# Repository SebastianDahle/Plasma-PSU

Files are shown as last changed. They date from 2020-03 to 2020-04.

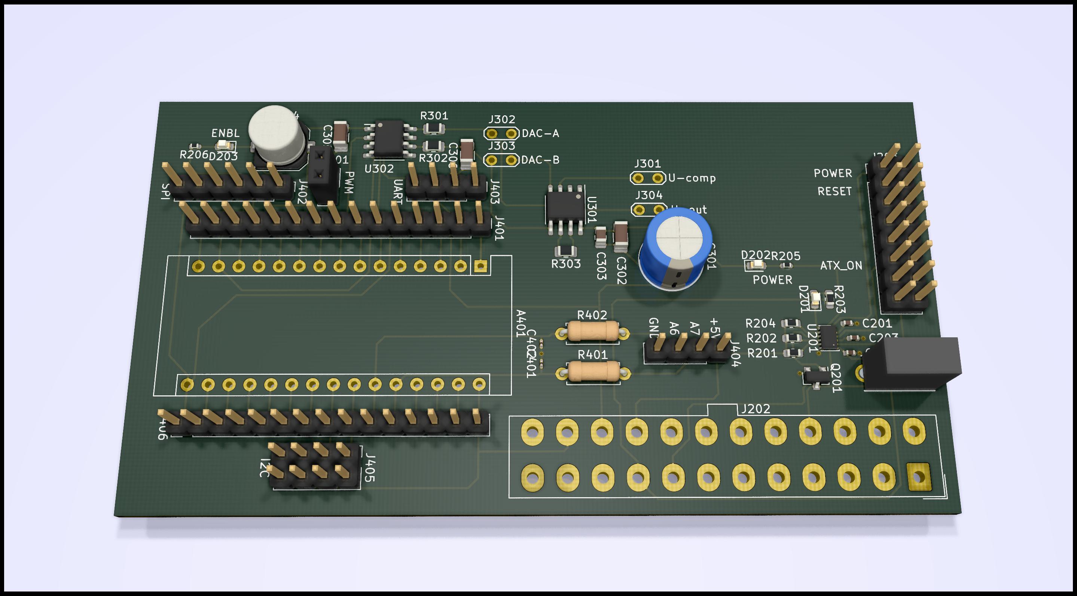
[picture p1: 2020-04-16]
Test-PCB_for_Arduino-DAC/Test-PCB_for_Arduino-DAC_002.jpg

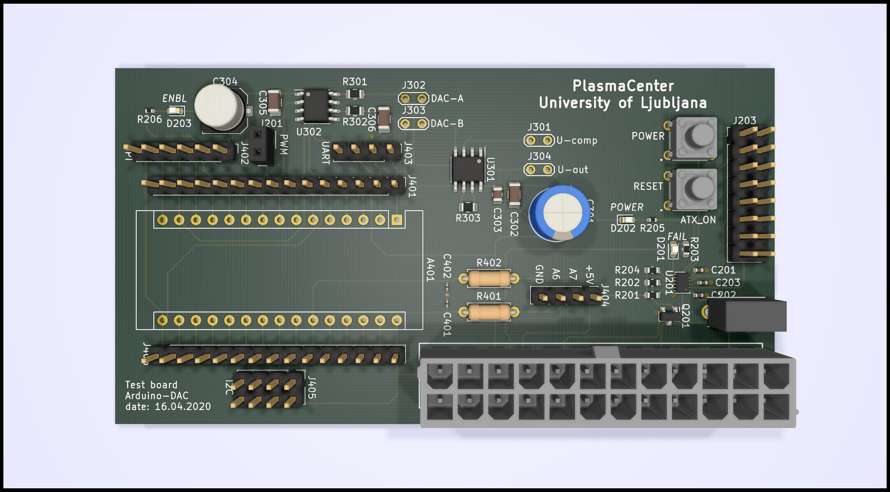
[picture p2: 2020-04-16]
Test-PCB_for_Arduino-DAC/Test-PCB_for_Arduino-DAC_004.jpg

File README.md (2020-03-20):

View this project on [CADLAB.io](https://cadlab.io/project/22638). 

# Plasma-PSU
Semi-professional HV power supply for various plasma applications, including Gliding Arcs, Dielectric Barrier Discharges, or School demonstrations. The design shall be suited for use in a laboratory environment, but simple and cheap to allow for uptake in DIY communities.

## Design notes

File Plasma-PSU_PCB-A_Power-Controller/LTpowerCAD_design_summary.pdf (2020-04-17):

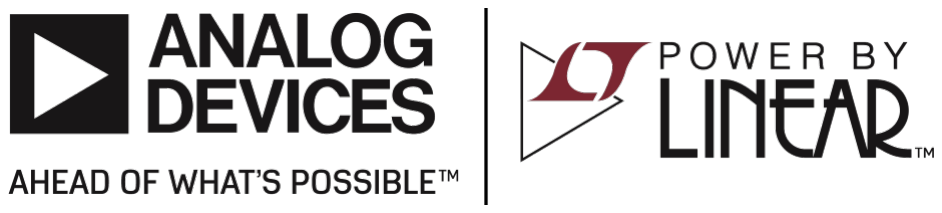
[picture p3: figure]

Printed : 04.17.2020 | Copyright © 2014 Analog Devices Inc.

## Designer :

## Project Date : 9/2014

## Project Name : Demo Board DC1641A

## Output Rails : Vout1 = 34,91V / 12A (max.)

## Vin : 10V (min.), 12V (nom.), 14V (max.)

# LTC3786 Supply Design Summary Report

## Output Rails : Vout1 = 34,91V / 12A (max.)

## Vin : 10V (min.), 12V (nom.), 14V (max.)

## LTC3786 Solution - Simplified Schematic

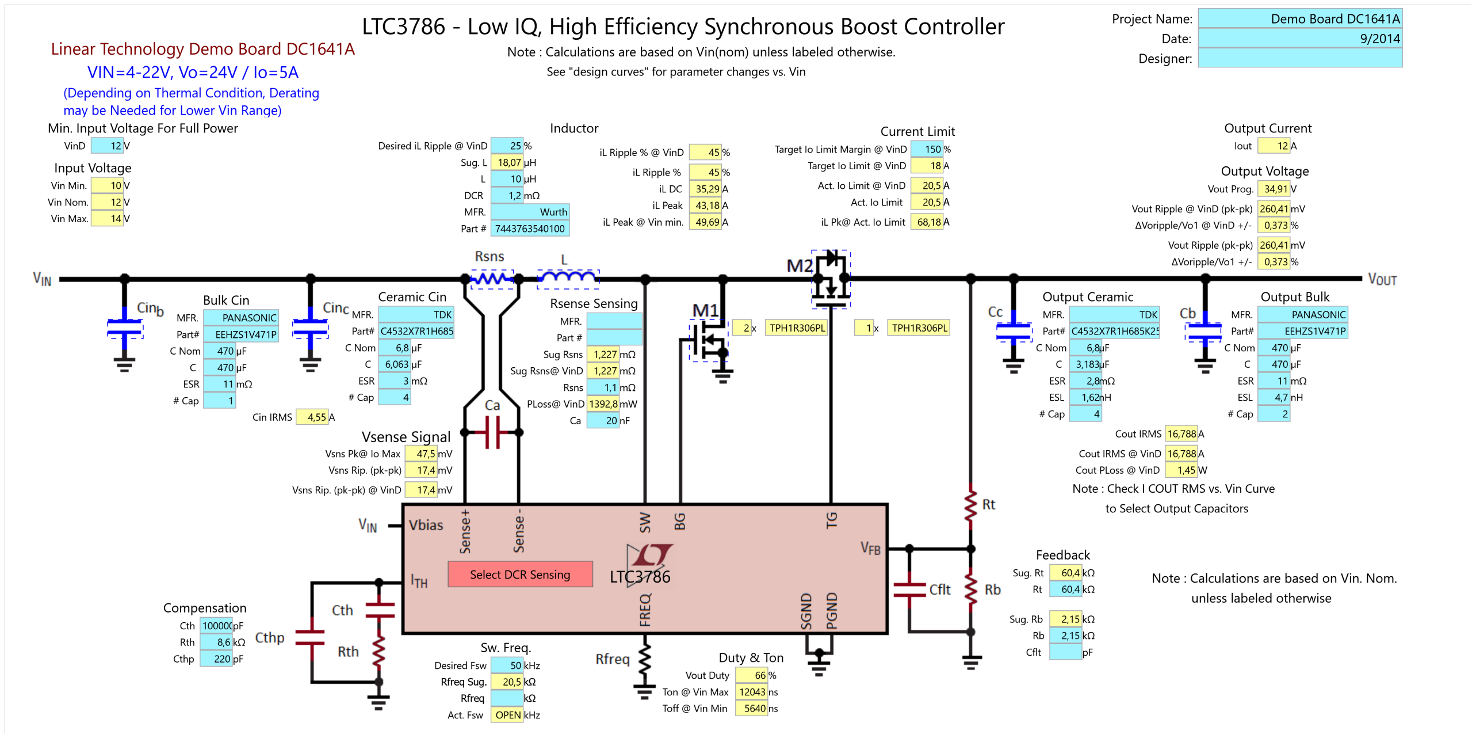
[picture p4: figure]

## Rail # 1 : Vin = 12V, Vout1 = 34,91V

## LTC3786 Solution - Efficiency & Loss Estimations

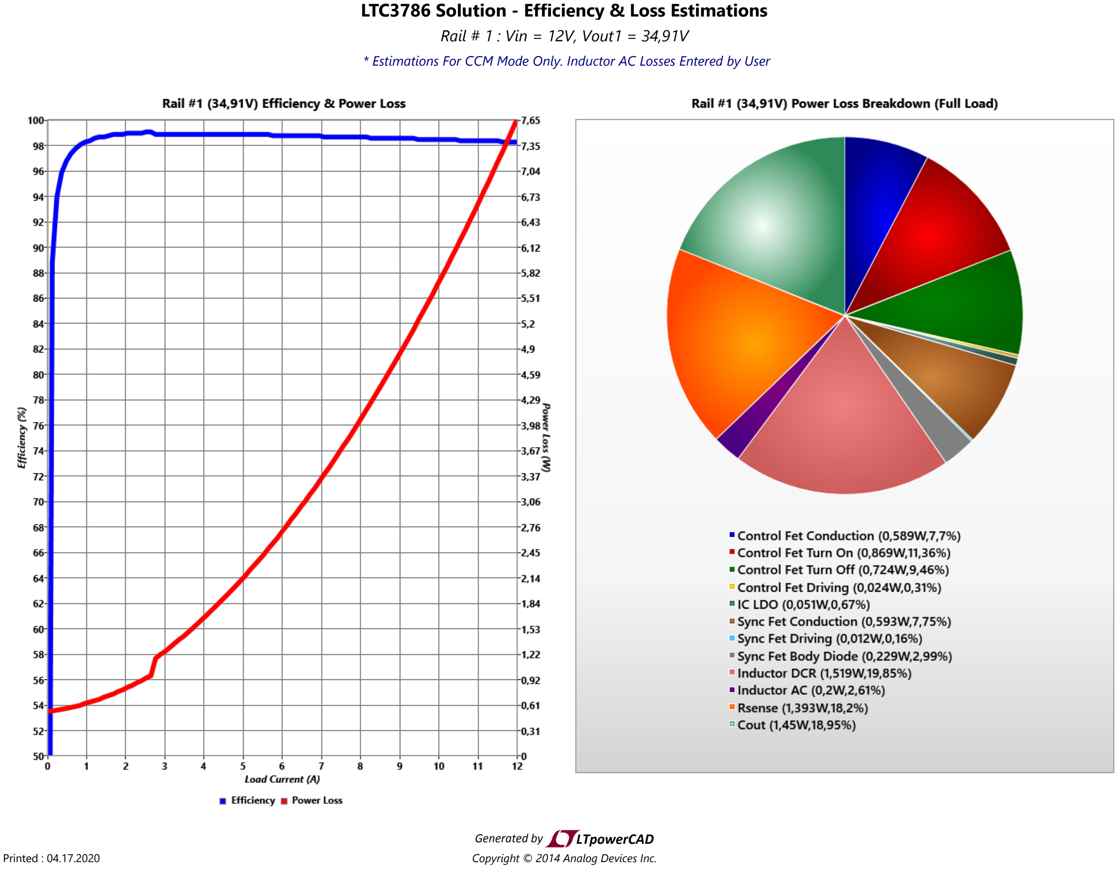
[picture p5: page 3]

### * Estimations For CCM Mode Only. Inductor AC Losses Entered by User

### * Estimations For CCM Mode Only. Estimations Based On Small Signal Avg. Model

## Rail # 1 : Vin = 12V, Vout1 = 34,91V, Iout1 = 1A

## LTC3786 Solution - Loop Gain & Load Transient Estimations

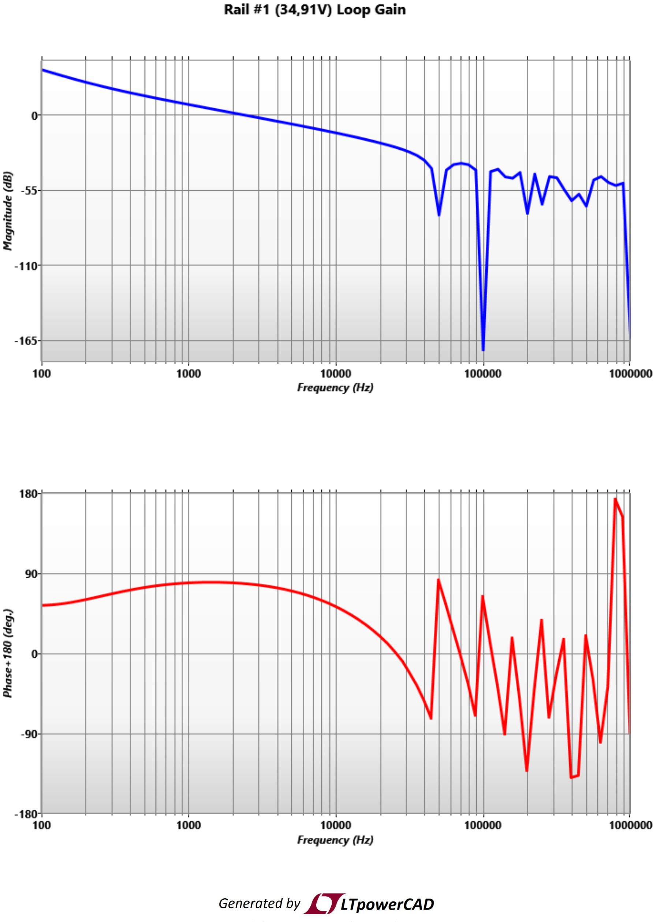
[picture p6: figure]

## LTC3786 Solution - Summary

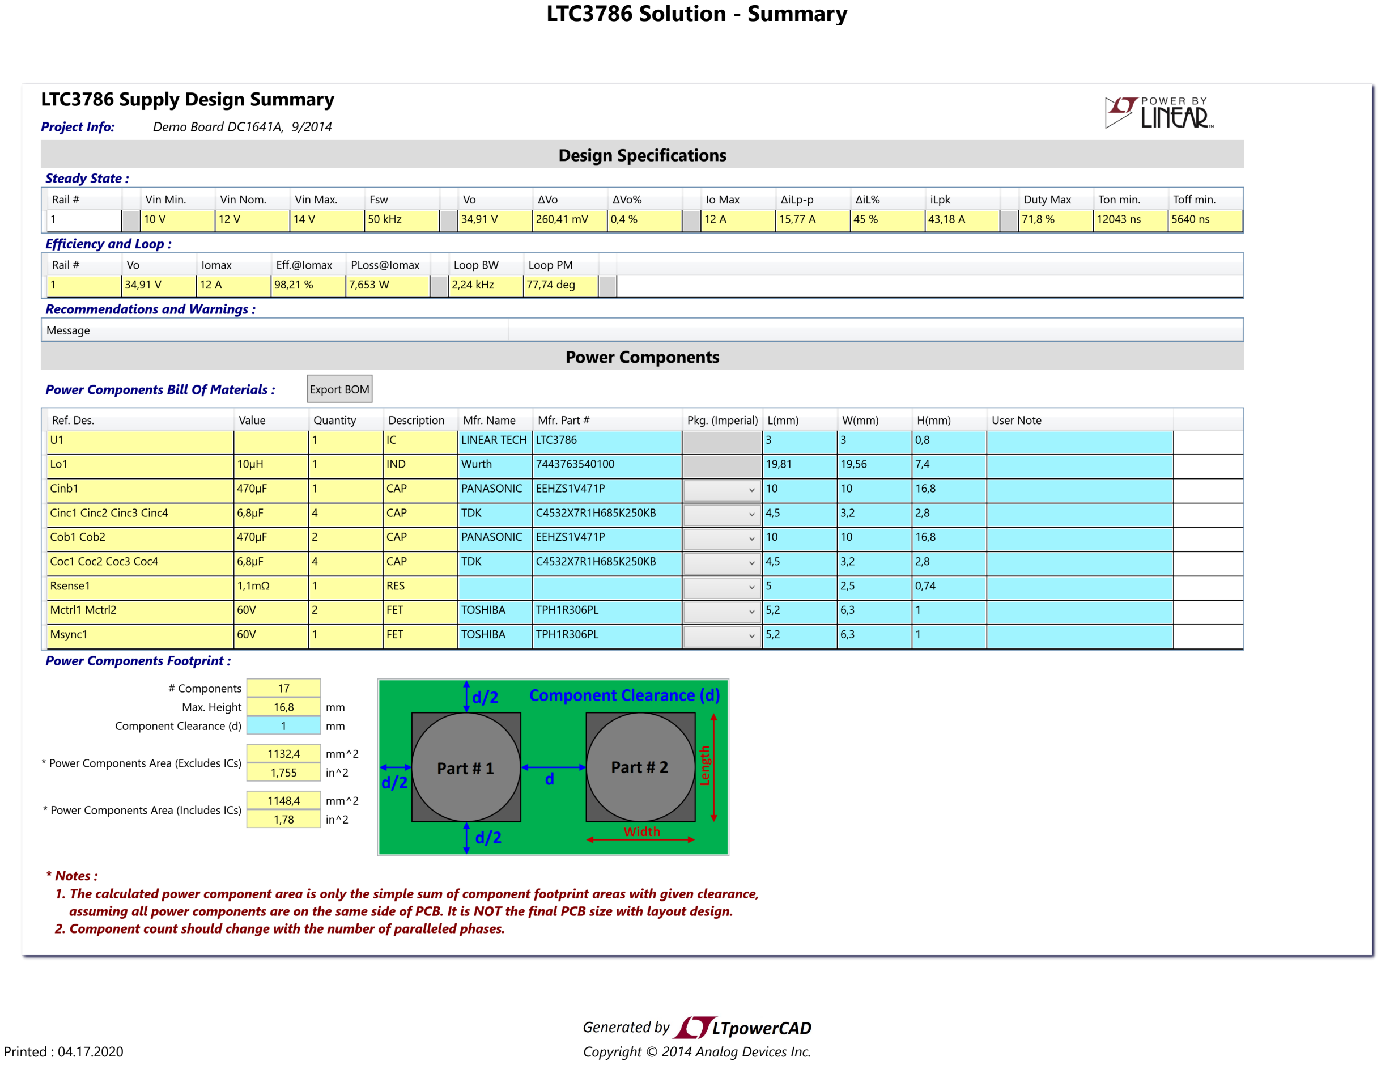
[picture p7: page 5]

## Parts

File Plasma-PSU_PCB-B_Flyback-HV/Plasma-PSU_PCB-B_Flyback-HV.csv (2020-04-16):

Reference | Quantity | Value | Footprint | Datasheet
C101 | 1 | 220 µF | Capacitor_THT:CP_Radial_D8.0mm_P3.50mm | ~
C102 C103 C104 C105 | 4 | 6.8 µF | Capacitor_THT:C_Disc_D6.0mm_W2.5mm_P5.00mm | ~
C106 | 1 | 100nF | Capacitor_SMD:C_1206_3216Metric | ~
C107 | 1 | 10nF | Capacitor_SMD:C_0805_2012Metric | ~
D101 | 1 | PWM_LED | LED_SMD:LED_0603_1608Metric | ~
D102 | 1 | ENBL_LED | LED_SMD:LED_0603_1608Metric | ~
D103 | 1 | ZD5 | Diode_THT:D_DO-41_SOD81_P7.62mm_Horizontal | ~
D104 | 1 | ZD20 | Diode_THT:D_DO-41_SOD81_P7.62mm_Horizontal | ~
D105 | 1 | UF4007 | Diode_THT:D_DO-41_SOD81_P7.62mm_Horizontal | ~
J101 | 1 | PWM_IN | Connector_PinHeader_2.54mm:PinHeader_1x02_P2.54mm_Vertical | ~
J102 | 1 | PWR_IN | TerminalBlock_Phoenix:TerminalBlock_Phoenix_MKDS-3-2-5.08_1x02_P5.08mm_Horizontal | ~
J103 | 1 | ENBL_IN | Connector_PinHeader_2.54mm:PinHeader_1x02_P2.54mm_Vertical | ~
J105 J106 J107 J108 J109 J104 | 6 | Conn_01x01_Female | MountingHole:MountingHole_3.2mm_M3_Pad_Via | ~
J110 | 1 | GND_SHIELD | TerminalBlock_Phoenix:TerminalBlock_Phoenix_MKDS-3-2-5.08_1x02_P5.08mm_Horizontal | ~
L101 | 1 | HV_Transformer | Plasma-PSU_PCB-B_Flyback-HV:HF-HV_Transformer_15kV_300W | ~
Q102 | 1 | TIP41C | Package_TO_SOT_THT:TO-220-3_Vertical | https://www.centralsemi.com/get_document.php?cmp=1&mergetype=pd&mergepath=pd&pdf_id=tip41.PDF
Q103 | 1 | TIP42C | Package_TO_SOT_THT:TO-220-3_Vertical | https://www.centralsemi.com/get_document.php?cmp=1&mergetype=pd&mergepath=pd&pdf_id=TIP42.PDF
Q104 Q101 | 2 | BT169B | Package_TO_SOT_THT:TO-92_Inline | https://media.digikey.com/pdf/Data%20Sheets/NXP%20PDFs/BT169_Series.pdf
Q105 | 1 | IPW60 | Package_TO_SOT_THT:TO-247-3_Vertical | ~
R102 R104 | 2 | 1k | Resistor_SMD:R_0603_1608Metric | ~
R103 R101 | 2 | 250R | Resistor_SMD:R_0603_1608Metric | ~
R105 | 1 | 300R | Resistor_SMD:R_0603_1608Metric | ~
R106 | 1 | 4R7 | Resistor_THT:R_Axial_DIN0207_L6.3mm_D2.5mm_P7.62mm_Horizontal | ~
U101 | 1 | L7812 | Package_TO_SOT_THT:TO-220-3_Vertical | http://www.st.com/content/ccc/resource/technical/document/datasheet/41/4f/b3/b0/12/d4/47/88/CD00000444.pdf/files/CD00000444.pdf/jcr:content/translations/en.CD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
U102 | 1 | L7805 | Package_TO_SOT_THT:TO-220-3_Vertical | http://www.st.com/content/ccc/resource/technical/document/datasheet/41/4f/b3/b0/12/d4/47/88/CD00000444.pdf/files/CD00000444.pdf/jcr:content/translations/en.CD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
U103 | 1 | ILD74 | Package_DIP:DIP-8_W7.62mm | https://www.vishay.com/docs/83640/ild74.pdf

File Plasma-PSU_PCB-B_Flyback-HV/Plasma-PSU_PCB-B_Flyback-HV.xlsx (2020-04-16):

Reference | Quantity for 1 board | Qty. 5x | Value | Footprint | ic-elect.si | si.farnell.com | mouser.at | Datasheet
C101 | 1 | 5 | 220 µF | Capacitor_THT:CP_Radial_D8.0mm_P3.50mm | 316005130100 | 1854019 | 667-EEU-FS1H221LB | ~
C102 C103 C104 C105 | 4 | 20 | 6.8 µF | Capacitor_THT:C_Disc_D6.0mm_W2.5mm_P5.00mm | 318001900100 | 9708332 | 581-TAP685K050SCS | ~
C106 | 1 | 5 | 100nF | Capacitor_SMD:C_1206_3216Metric | 313510655001 | 3296165 (x10kos) | 80-C1206C104K5R7210 | ~
C107 | 1 | 5 | 10nF | Capacitor_SMD:C_0805_2012Metric | 313410633101 | 2896776 (x5 kos) | 710-885012207092 | ~
D101, D102 | 2 | 10 | PWM_LED, ENBL_LED | LED_SMD:LED_0603_1608Metric | 198100082000 | 2290329 (x5 kos) | 710-150060SS75000 | ~
D103 | 1 | 5 | ZD5 | Diode_THT:D_DO-41_SOD81_P7.62mm_Horizontal | 161000600100 | 1861448 (x5 kos) | 78-1N4734A | ~
D104 | 1 | 5 | ZD20 | Diode_THT:D_DO-41_SOD81_P7.62mm_Horizontal | 161001900100 | 2132575 | 78-1N4747A | ~
D105 | 1 | 5 | UF4007 | Diode_THT:D_DO-41_SOD81_P7.62mm_Horizontal | 159040070302 | 1467503 (x5 kos) | 625-UF4007-E3 | ~
J101, J103 | 1 | 5 | PWM_IN, ENBL_IN | Connector_PinHeader_2.54mm:PinHeader_1x02_P2.54mm_Vertical | n.a. | n.a. | 855-M20-9990246 | ~
J102, J110 | 2 | 10 | PWR_IN, GND_SHIELD | TerminalBlock_Phoenix:TerminalBlock_Phoenix_MKDS-3-2-5.08_1x02_P5.08mm_Horizontal | 261010380200 | 3714240 | 651-1712339 | ~
J105 J106 J107 J108 J109 J104 | 6 | 30 | Conn_01x01_Female | MountingHole:MountingHole_3.2mm_M3_Pad_Via | - | - | - | ~
L101 | 1 | 5 | HV_Transformer | Plasma-PSU_PCB-B_Flyback-HV:HF-HV_Transformer_15kV_300W | - | - | - | ~
Q102 | 1 | 5 | TIP41C | Package_TO_SOT_THT:TO-220-3_Vertical | n.a. | 1574341 | 511-TIP41C | https://www.centralsemi.com/get_document.php?cmp=1&mergetype=pd&mergepath=pd&pdf_id=tip41.PDF
Q103 | 1 | 5 | TIP42C | Package_TO_SOT_THT:TO-220-3_Vertical | 72000420301 | 1574342 | 511-TIP42C | https://www.centralsemi.com/get_document.php?cmp=1&mergetype=pd&mergepath=pd&pdf_id=TIP42.PDF
Q104 Q101 | 2 | 10 | BT169B | Package_TO_SOT_THT:TO-92_Inline | n.a. | 3358390 | 771-BT169D,126 | https://media.digikey.com/pdf/Data%20Sheets/NXP%20PDFs/BT169_Series.pdf
Q105 | 1 | 5 | IPW60 | Package_TO_SOT_THT:TO-247-3_Vertical | n.a. | 2709900 | 726-IPW60R070P6 | ~
R102 R104 | 2 | 10 | 1k | Resistor_SMD:R_0603_1608Metric | 209631000101 | 1469740 (x10 kos) | 71-CRCW06031K00JNEAC | ~
R103 R101 | 2 | 10 | 250R | Resistor_SMD:R_0603_1608Metric | 209623000101 | 2447307 | 71-CRCW0603-261-E3 | ~
R105 | 1 | 5 | 300R | Resistor_SMD:R_0603_1608Metric | 209623000101 | 2447331 | 71-CRCW0603-300-E3 | ~
R106 | 1 | 5 | 4R7 | Resistor_THT:R_Axial_DIN0207_L6.3mm_D2.5mm_P7.62mm_Horizontal | 213004700100 | 1903712 | 594-5073NW4R700J | ~
U101 | 1 | 5 | L7812 | Package_TO_SOT_THT:TO-220-3_Vertical | 35078120200 | 1087090 | 511-L7812CV | http://www.st.com/content/ccc/resource/technical/document/datasheet/41/4f/b3/b0/12/d4/47/88/CD00000444.pdf/files/CD00000444.pdf/jcr:content/translations/en.CD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
U102 | 1 | 5 | L7805 | Package_TO_SOT_THT:TO-220-3_Vertical | 35078050200 | 9756078 | 511-L7805CV | http://www.st.com/content/ccc/resource/technical/document/datasheet/41/4f/b3/b0/12/d4/47/88/CD00000444.pdf/files/CD00000444.pdf/jcr:content/translations/en.CD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
U103 | 1 | 5 | ILD74 | Package_DIP:DIP-8_W7.62mm | 203004400100 | 1045423 | 782-ILD74 | https://www.vishay.com/docs/83640/ild74.pdf
for U103 | 1 | 5 | DIP-8 socket | Package_DIP:DIP-8_W7.62mm | 335000080100 | 1077344 (https://si.farnell.com/amp-te-connectivity/808-ag11d-esl-lf/socket-ic-dil-8way/dp/1077344?st=ic%20socket%20dip) | 571-1-2199298-2

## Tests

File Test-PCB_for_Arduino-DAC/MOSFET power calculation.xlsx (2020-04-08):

 |  | IPB60R040CFD7ATMA1 | SIR120DP-T1-RE3 | SIHG039N60EF-GE3 | IPT019N08N5ATMA1 | IXTT240N15X4HV | NVMFD6H840NLWFT1G | NVTFS6H850NLTAG | IXFQ50N60X | IXFT150N30X3HV
 | Vout | 24 | 24 | 24 | 24 | 24 | 24 | 36 | 24 | 24
 | Vin | 12 | 12 | 12 | 12 | 12 | 12 | 12 | 12 | 12
 | Iout,max | 15 | 15 | 15 | 15 | 15 | 15 | 11 | 15 | 15
 | Rdson | 0.04 | 0.00355 | 0.04 | 0.0019 | 0.0036 | 0.0069 | 0.0086 | 0.073 | 0.0083
 | delta | 0.005 | 0.005 | 0.005 | 0.005 | 0.005 | 0.005 | 0.005 | 0.005 | 0.005
 | k | 1.7 | 1.7 | 1.7 | 1.7 | 1.7 | 1.7 | 1.7 | 1.7 | 1.7
 | Cmiller | 2.14e-08 | 1.25e-08 | 1.68e-08 | 2.02e-08 | 3.9e-08 | 6.4e-09 | 2.6e-09 | 2.32e-08 | 3.54e-08
 | Qg | 1.07e-07 | 6.25e-08 | 8.4e-08 | 1.01e-07 | 1.95e-07 | 3.2e-08 | 1.3e-08 | 1.16e-07 | 1.77e-07
 | f | 350000 | 350000 | 350000 | 350000 | 350000 | 350000 | 350000 | 350000 | 350000
TS | Psync | 18.09 | 1.61 | 18.09 | 0.86 | 1.63 | 3.12 | 3.14 | 33.01 | 3.75
BS | Pmain | 238.12 | 130.13 | 190.82 | 208.55 | 402.61 | 68.92 | 72.44 | 271.55 | 367.72
 | Pmax | 227 | 100 | 357 | 231 | 940 | 90 | 73 | 660 | 890
 | Unit price |  |  |  |  | 17.53 € |  | 0.74 € |  | 16.16 €
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

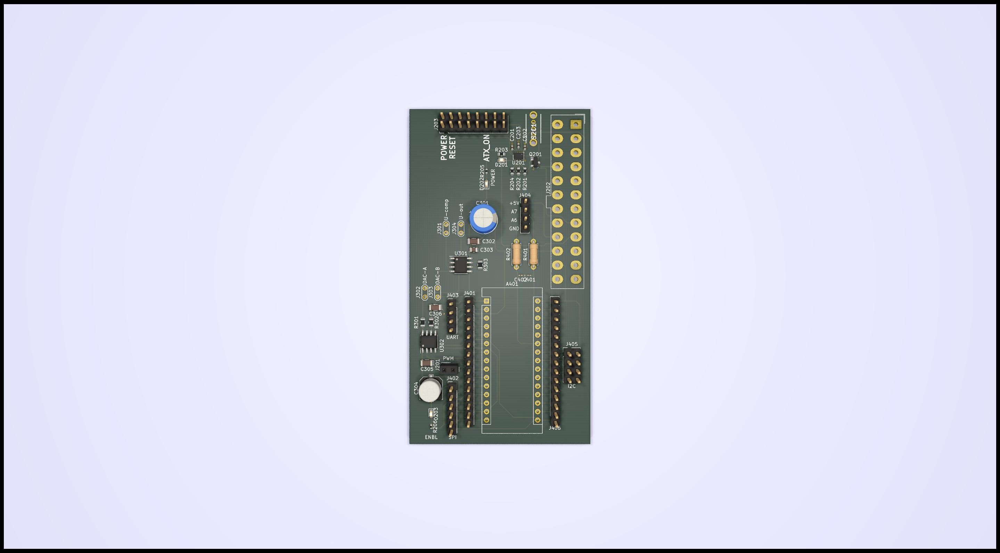
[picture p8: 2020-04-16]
Test-PCB_for_Arduino-DAC/Test-PCB_for_Arduino-DAC_001.jpg

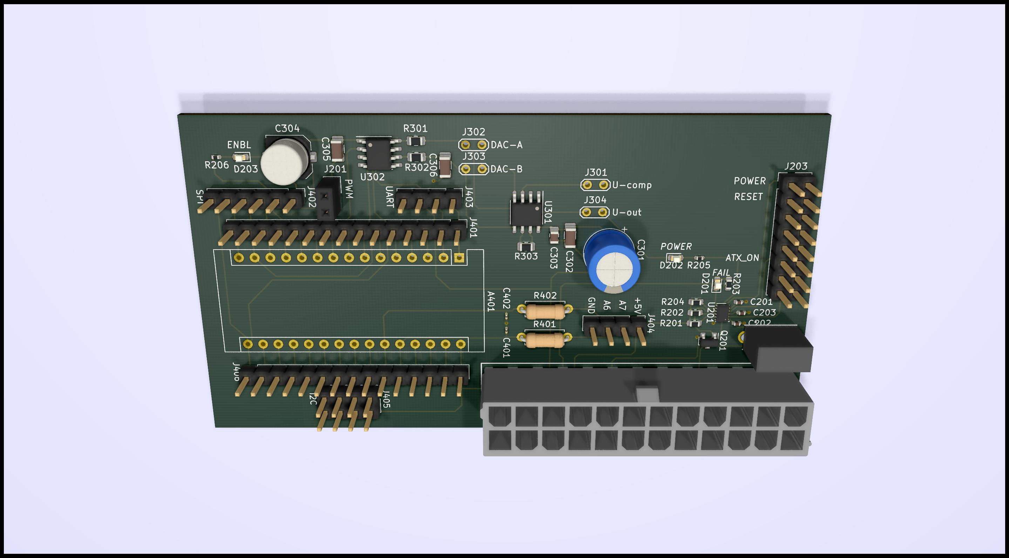
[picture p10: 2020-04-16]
Test-PCB_for_Arduino-DAC/Test-PCB_for_Arduino-DAC_003.jpg

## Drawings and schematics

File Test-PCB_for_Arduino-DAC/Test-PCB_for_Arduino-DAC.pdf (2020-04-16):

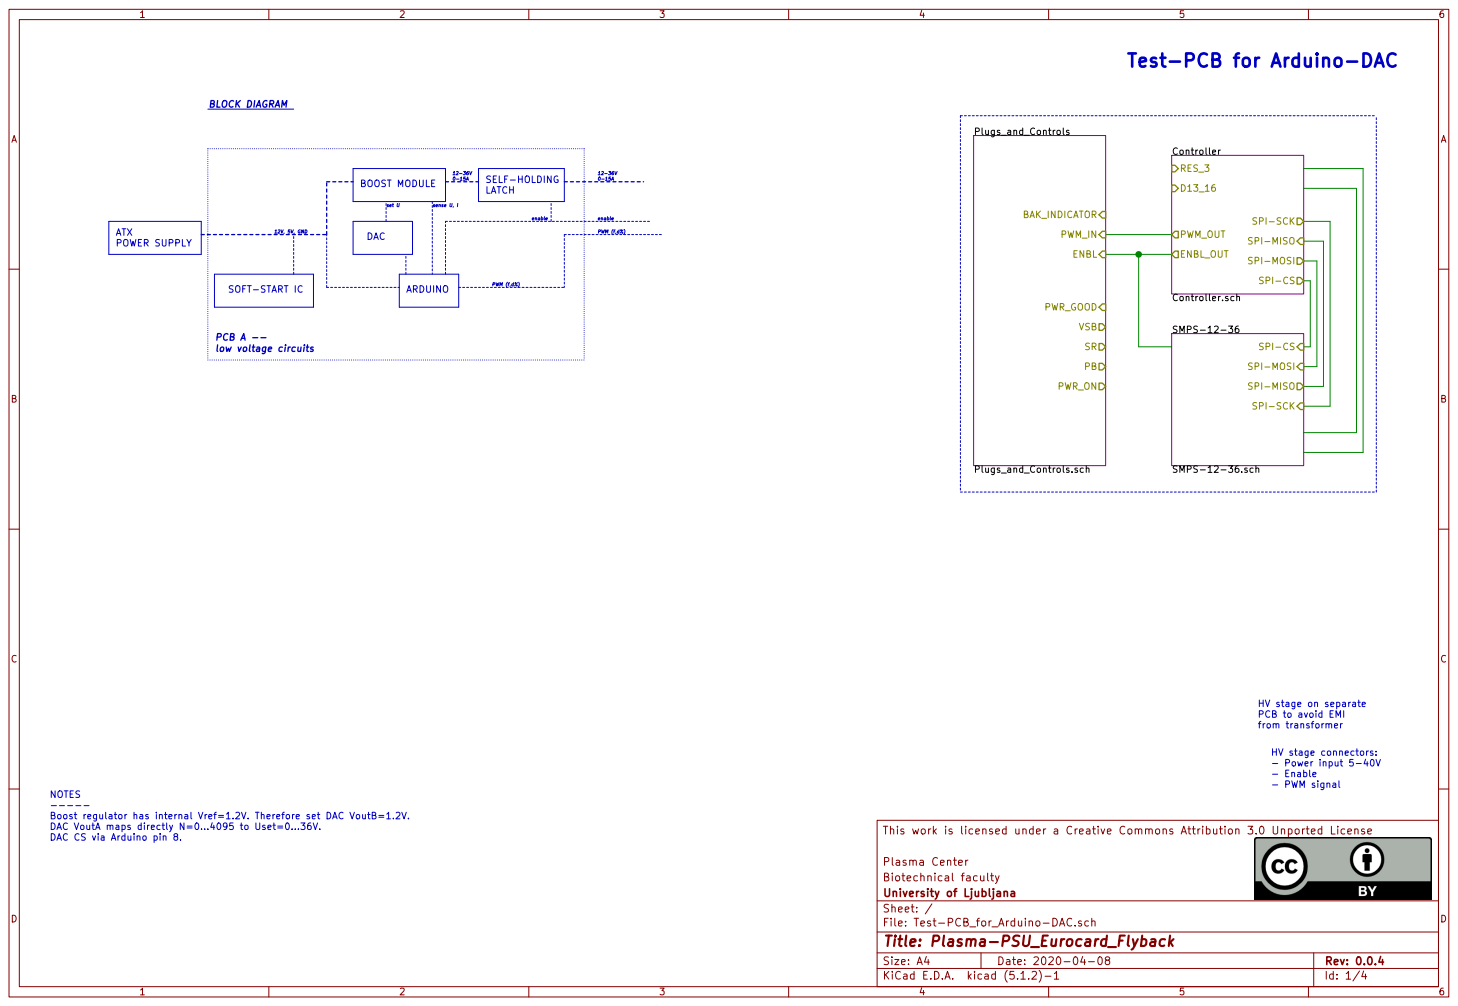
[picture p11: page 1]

low voltage circuits BLOCK DIAGRAM
12V, 5V, GND NOTES

from transformer Test-PCB for Arduino-DAC
Plugs_and_Controls.schENBL BAK_INDICATOR

SPI-MOSI SPI-CS RES_3 D13_16

HV stage on separate PCB to avoid EMI

----- Boost regulator has internal Vref=1.2V. Therefore set DAC VoutB=1.2V.

DAC VoutA maps directly N=0...4095 to Uset=0...36V.
DAC CS via Arduino pin 8.

Biotechnical faculty Plasma Center This work is licensed under a Creative Commons Attribution 3.0 Unported License

File: Test-PCB_for_Arduino-DAC.sch Sheet: / University of Ljubljana

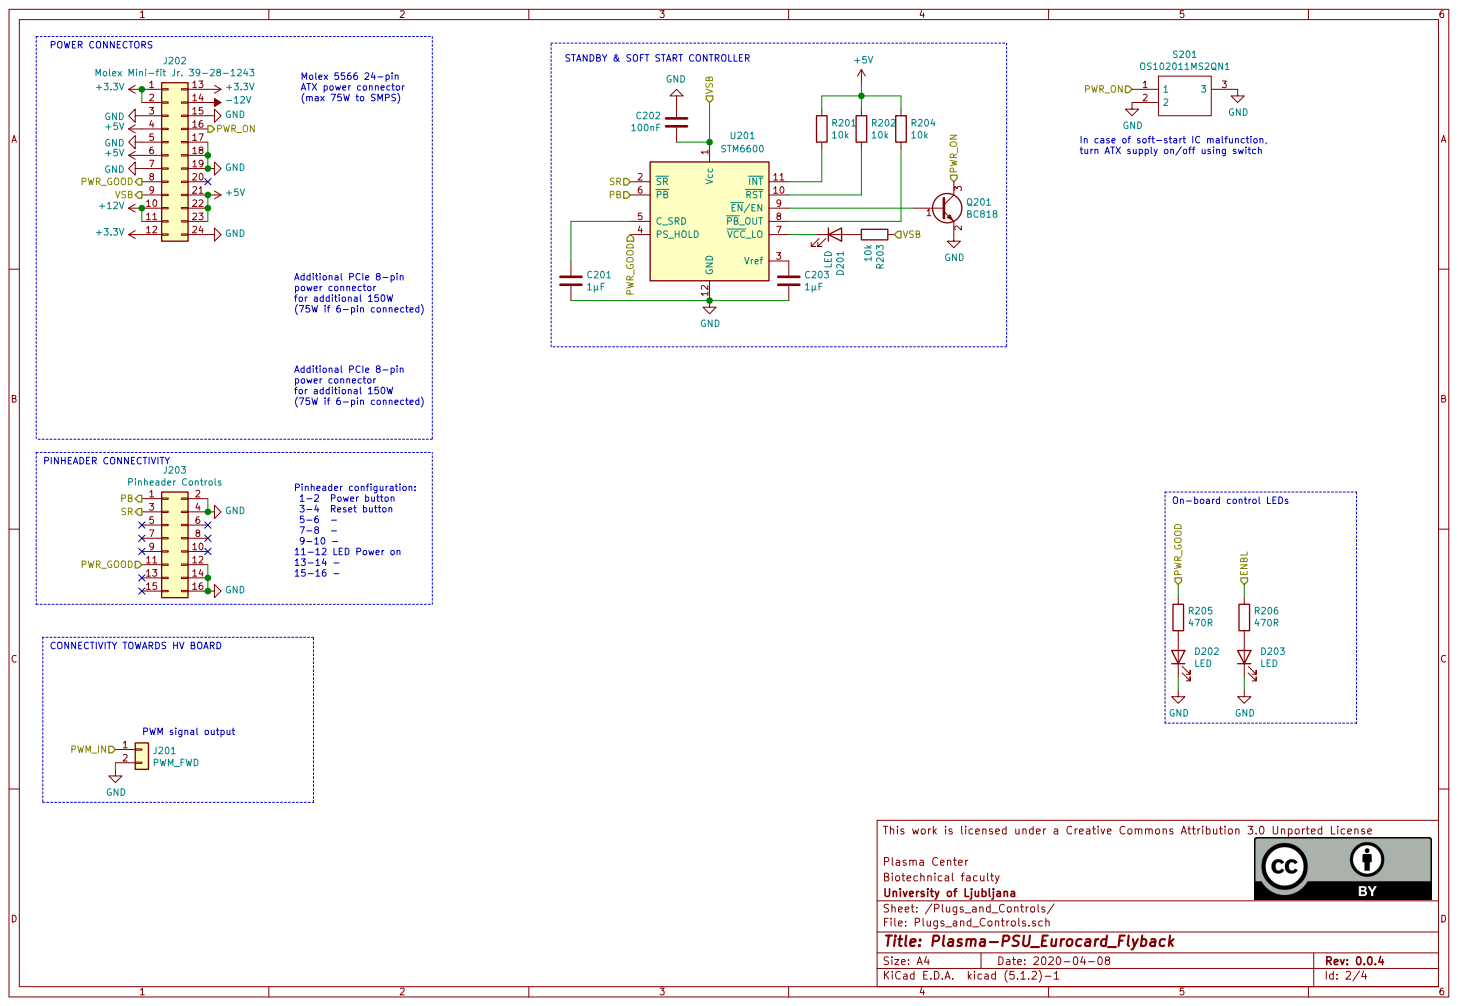
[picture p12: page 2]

J202 Molex Mini-fit Jr. 39-28-1243 PWR_ON

STANDBY & SOFT START CONTROLLER

(max 75W to SMPS) PINHEADER CONNECTIVITY

In case of soft-start IC malfunction,
turn ATX supply on/off using switch

Additional PCIe 8-pin power connector

CONNECTIVITY TOWARDS HV BOARD

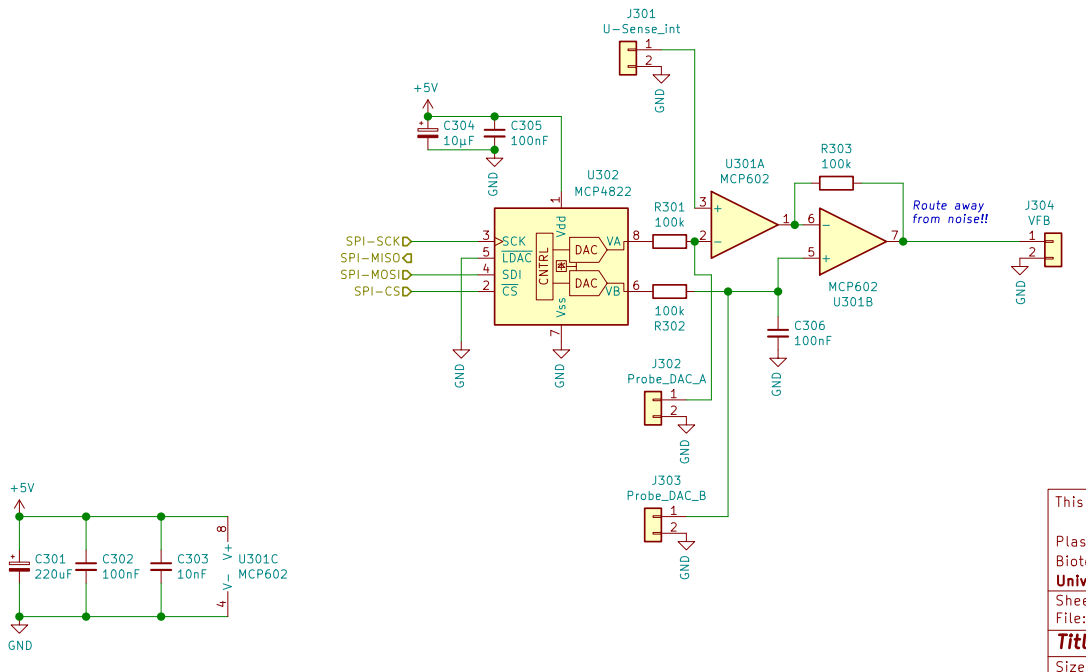
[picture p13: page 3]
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

File: SMPS-12-36.sch Sheet: /SMPS-12-36/ University of Ljubljana

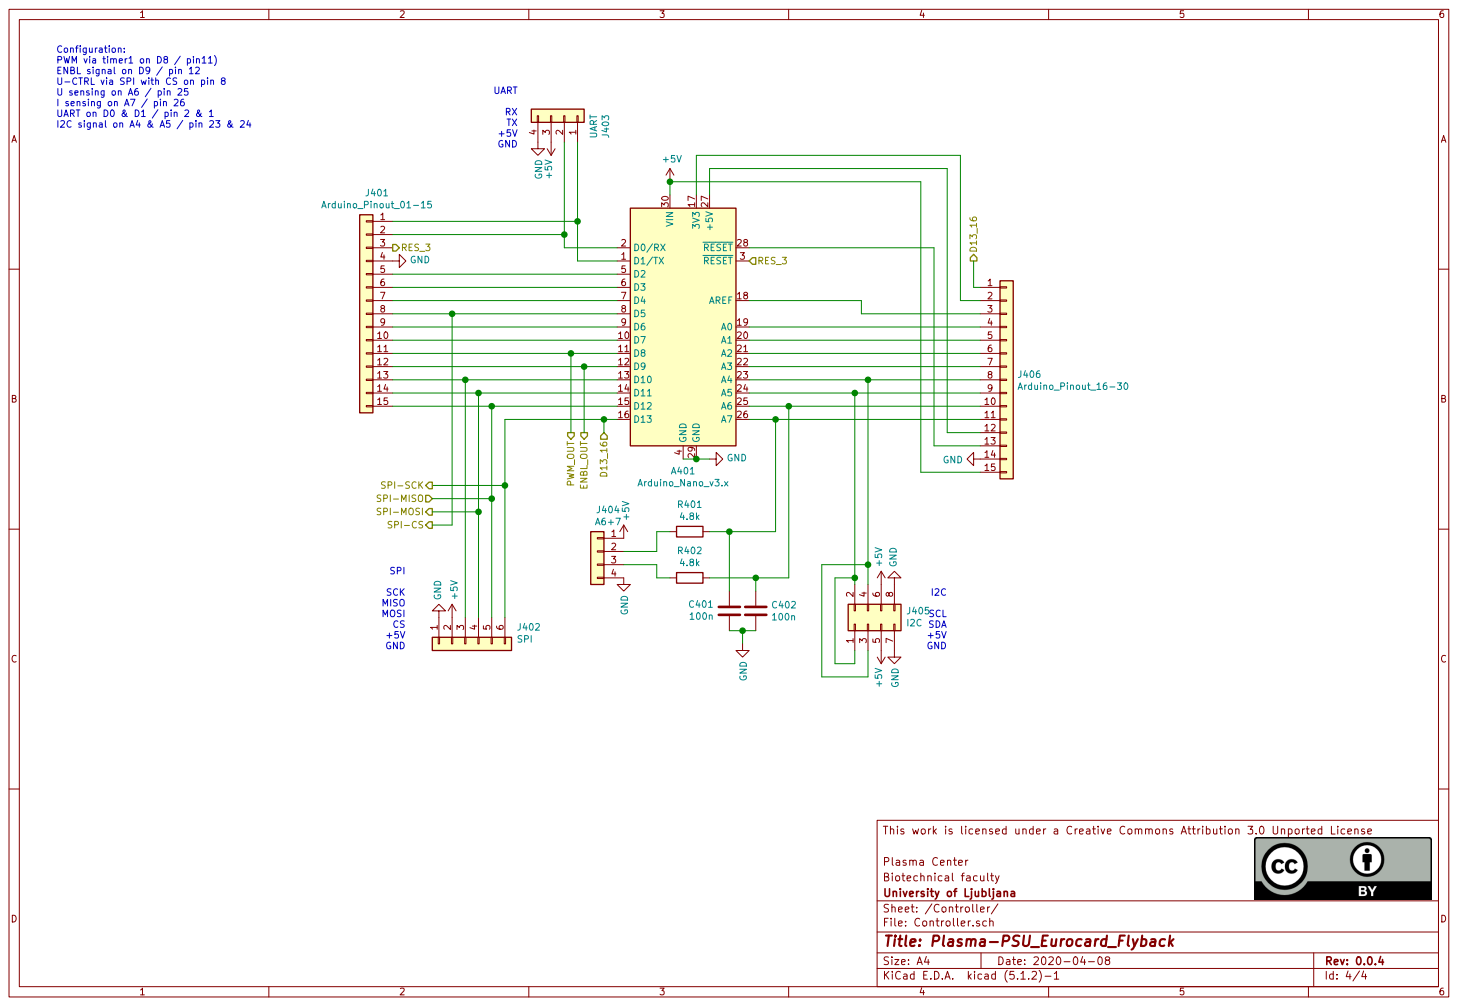
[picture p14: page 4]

Configuration:
PWM via timer1 on D8 / pin11)
ENBL signal on D9 / pin 12
U-CTRL via SPI with CS on pin 8
U sensing on A6 / pin 25
I sensing on A7 / pin 26
UART on D0 & D1 / pin 2 & 1
I2C signal on A4 & A5 / pin 23 & 24

10 | 5
11 | 6
12 | | 7
13 | | | 8
14 | | | | 9
15 | | | | | 10

11
12

100n SPI SCK MISO MOSI CS

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

File: Controller.sch Sheet: /Controller/ University of Ljubljana

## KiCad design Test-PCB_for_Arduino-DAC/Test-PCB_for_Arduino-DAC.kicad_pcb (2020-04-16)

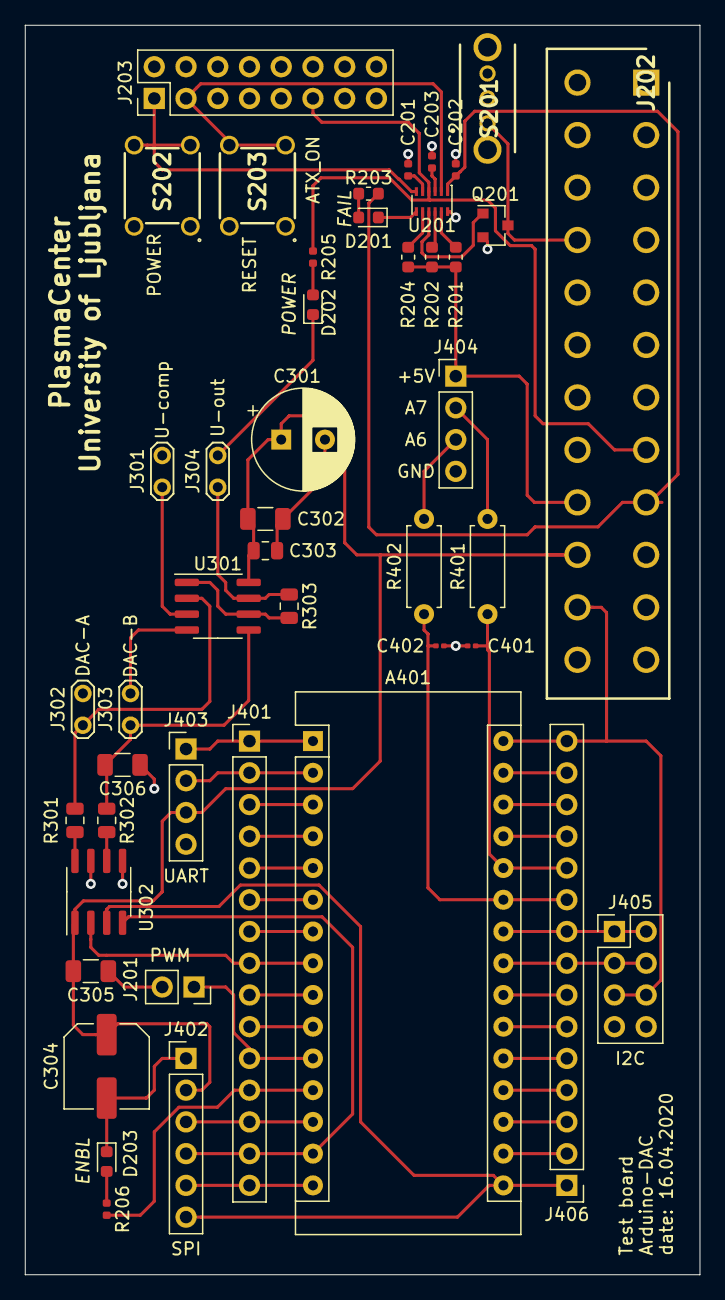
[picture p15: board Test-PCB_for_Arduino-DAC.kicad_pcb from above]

Board: 2 copper layers, 54.0 x 100.0 mm, 46 parts (0 on the bottom side), 55 nets.

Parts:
A401: Arduino_Nano_v3.x; Arduino_Nano
C201, C203: 1µF; C_0402_1005Metric
C202: 100nF; C_0402_1005Metric
C301: 220uF; CP_Radial_D8.0mm_P3.50mm
C302, C305, C306: 100nF; C_1206_3216Metric
C303: 10nF; C_0805_2012Metric
C304: 10µF; C_Elec_6.3x5.8
C401, C402: 100n; C_0201_0603Metric
D201, D202, D203: LED; LED_0603_1608Metric
J201: PWM_FWD; PinSocket_1x02_P2.54mm_Vertical
J202: 39-28-1243; SHDR24W120P550X420_2X12_5160X960X1310P
J203: Pinheader Controls; PinHeader_2x08_P2.54mm_Vertical
J301: U-Sense_int; TestPoint_2Pads_Pitch2.54mm_Drill0.8mm
J302: Probe_DAC_A; TestPoint_2Pads_Pitch2.54mm_Drill0.8mm
J303: Probe_DAC_B; TestPoint_2Pads_Pitch2.54mm_Drill0.8mm
J304: VFB; TestPoint_2Pads_Pitch2.54mm_Drill0.8mm
J401: Arduino_Pinout_01-15; PinHeader_1x15_P2.54mm_Vertical
J402: SPI; PinHeader_1x06_P2.54mm_Vertical
J403: UART; PinHeader_1x04_P2.54mm_Vertical
J404: A6+7; PinHeader_1x04_P2.54mm_Vertical
J405: I2C; PinHeader_2x04_P2.54mm_Vertical
J406: Arduino_Pinout_16-30; PinHeader_1x15_P2.54mm_Vertical
Q201: BC818; SOT-23
R201, R202, R203, R204: 10k; R_0603_1608Metric
R205, R206: 470R; R_0402_1005Metric
R301, R302, R303: 100k; R_0805_2012Metric
R401, R402: 4.8k; R_Axial_DIN0207_L6.3mm_D2.5mm_P7.62mm_Horizontal
S201: OS102011MS2QN1; OS102011MA1QN1
S202, S203: 1825910-6
U201: STM6600; TDFN-12_2x3mm_P0.5mm
U301: MCP602; SOIC-8_3.9x4.9mm_P1.27mm
U302: MCP4822; SOIC-8_3.9x4.9mm_P1.27mm

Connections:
+3V3: J202.1, J202.2, J202.3, J202.23
+5V: A401.30, C301.1, C302.1, C303.1, C304.1, C305.1, J202.7, J202.11, J202.18, J202.20, J202.22, J402.2, J403.3, J404.1, J405.5, J405.6, J406.15, R201.1, R202.1, R204.1, U301.8, U302.1
+12V: J202.19, J202.21
/Controller/D13_16: A401.16, J402.6, J406.1, U302.3
/Controller/RES_3: A401.3, J401.3
/Controller/SPI-CS: A401.8, J401.8, U302.2
/Controller/SPI-MISO: A401.15, J401.15, J402.5
/Controller/SPI-MOSI: A401.14, J401.14, J402.4, U302.4
/Plugs_and_Controls/ENBL: A401.12, J401.12, R206.2
/Plugs_and_Controls/PB: J203.1, S202.3, S202.4, U201.6
/Plugs_and_Controls/PWM_IN: A401.11, J201.1, J401.11
/Plugs_and_Controls/PWR_GOOD: J202.15, J203.11, R205.2, U201.4
/Plugs_and_Controls/PWR_ON: J202.8, Q201.3, S201.1
/Plugs_and_Controls/SR: J203.3, S203.3, S203.4, U201.2
/Plugs_and_Controls/VSB: C202.1, J202.17, R203.1, U201.1
GND: A401.4, A401.29, C201.2, C202.2, C203.2, C301.2, C302.2, C303.2, C304.2, C305.2, C306.2, C401.1, C402.2, D202.1, D203.1, J201.2, J202.5, J202.6, J202.9, J202.10, J202.12, J202.13, J202.14, J202.24, J203.2, J203.4, J203.12, J203.14, J203.16, J301.2, J302.2, J303.2, J304.2, J401.4, J402.1, J403.4, J404.4, J405.7, J405.8, J406.14, Q201.2, S201.2, S201.3, S202.1, S202.2, S203.1, S203.2, U201.12, U301.4, U302.5, U302.7
unnamed: A401.1, J401.1, J403.1
unnamed: A401.2, J401.2, J403.2
unnamed: A401.5, J401.5
unnamed: A401.6, J401.6
unnamed: A401.7, J401.7
unnamed: A401.9, J401.9
unnamed: A401.10, J401.10
unnamed: A401.13, J401.13, J402.3
unnamed: A401.17, J406.2
unnamed: A401.18, J406.3
unnamed: A401.19, J406.4
unnamed: A401.20, J406.5
unnamed: A401.21, J406.6
unnamed: A401.22, J406.7
unnamed: A401.23, J405.3, J405.4, J406.8
unnamed: A401.24, J405.1, J405.2, J406.9
unnamed: A401.25, C402.1, J406.10, R402.1
unnamed: A401.26, C401.2, J406.11, R401.1
unnamed: A401.27, J406.12
unnamed: A401.28, J406.13
unnamed: C201.1, U201.5
unnamed: C203.1, U201.3
unnamed: C306.1, J303.1, R302.1, U301.5
unnamed: D201.1, U201.7
unnamed: D201.2, R203.2
unnamed: D202.2, R205.1
unnamed: D203.2, R206.1
unnamed: J301.1, U301.3
unnamed: J302.1, R301.1, U301.2
unnamed: J304.1, R303.1, U301.7
unnamed: J404.2, R401.2
unnamed: J404.3, R402.2
unnamed: Q201.1, U201.9
unnamed: R201.2, U201.11
unnamed: R202.2, U201.10
unnamed: R204.2, U201.8
unnamed: R301.2, U302.8
unnamed: R302.2, U302.6
unnamed: R303.2, U301.1, U301.6

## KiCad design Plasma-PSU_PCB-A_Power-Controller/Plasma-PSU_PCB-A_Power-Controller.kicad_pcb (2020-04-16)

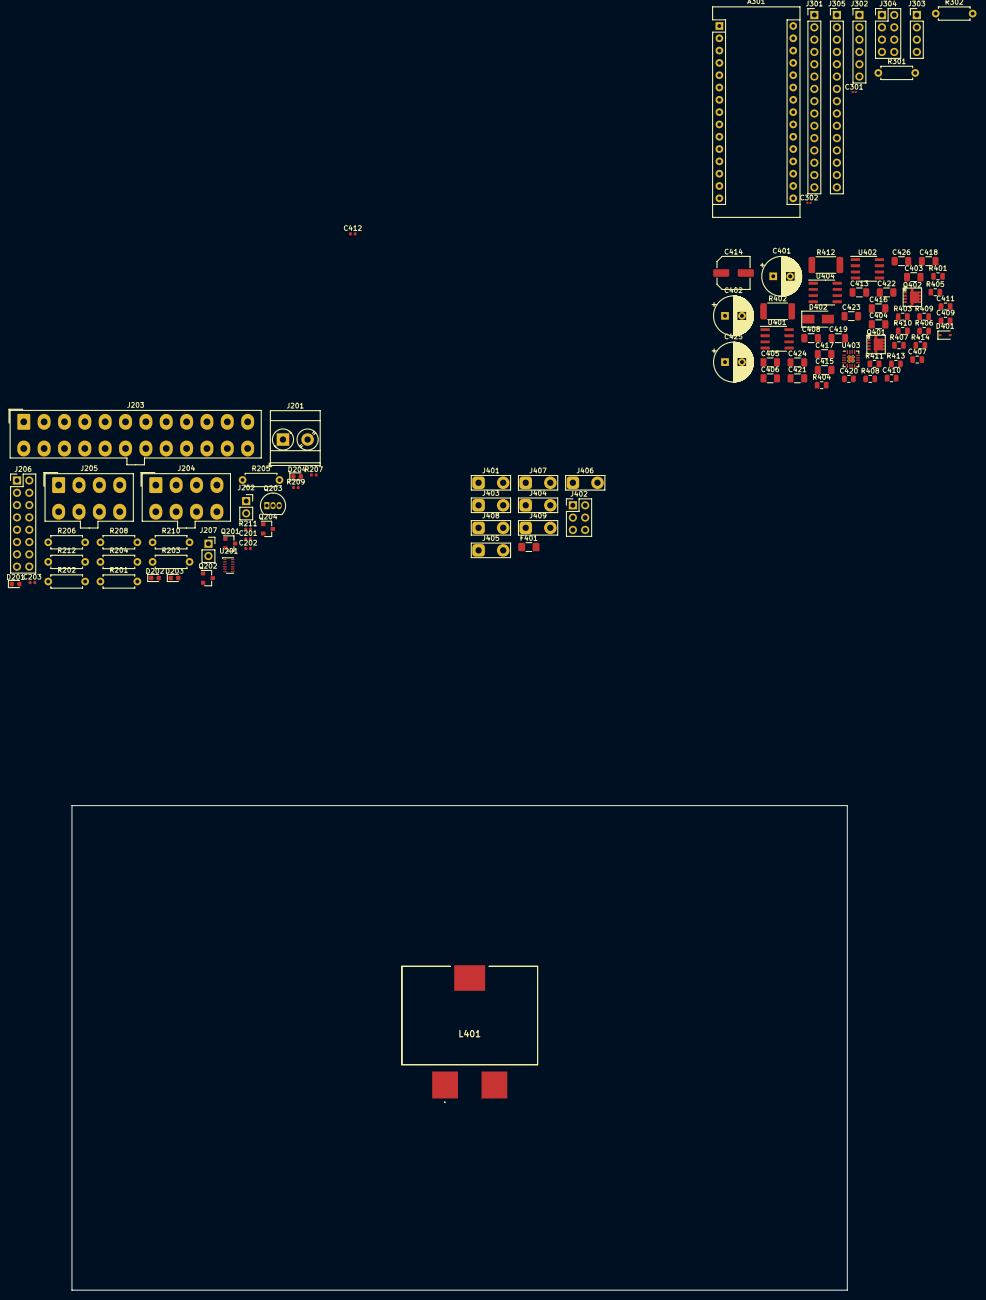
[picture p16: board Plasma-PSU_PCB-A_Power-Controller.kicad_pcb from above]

Board: 2 copper layers, 160.0 x 100.0 mm, 100 parts (0 on the bottom side), 82 nets, no tracks yet.

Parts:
A301: Arduino_Nano_v3.x; Arduino_Nano
C201, C203: 1µF; C_0402_1005Metric
C202: 100nF; C_0402_1005Metric
C301, C302: 100n; C_0201_0603Metric
C401, C402, C425: 220uF; CP_Radial_D8.0mm_P3.50mm
C403, C404, C422, C423, C424: 6.8µF; C_1206_3216Metric
C405, C406, C408, C413, C415, C416, C417, C419, C421, C426: 100nF; C_1206_3216Metric
C407, C409, C420: 10nF; C_0805_2012Metric
C410: 15nF; C_0805_2012Metric
C411: 220pF; C_0805_2012Metric
C412: 100pF; C_0402_1005Metric
C414: 10µF; C_Elec_6.3x5.8
C418: 4.7µ MLCC; C_1206_3216Metric
D201, D202, D203, D204: LED; LED_0603_1608Metric
D401: ZD5; D_SOD-323
D402: B120-E3; D_SMA
F401: Bel 0685P9120-01; Fuse_1206_3216Metric_Pad1.42x1.75mm_HandSolder
J201: PWR_FWD; TerminalBlock_Phoenix_MKDS-3-2-5.08_1x02_P5.08mm_Horizontal
J202: PWM_FWD; PinSocket_1x02_P2.54mm_Vertical
J203: Molex Mini-fit Jr. 39-28-1243; Molex_Mini-Fit_Jr_5566-24A_2x12_P4.20mm_Vertical
J204, J205: Molex Mini-fit Jr. 39-28-1083; Molex_Mini-Fit_Jr_5566-08A_2x04_P4.20mm_Vertical
J206: Pinheader Controls; PinHeader_2x08_P2.54mm_Vertical
J207: ENBL_FWD; PinSocket_1x02_P2.54mm_Vertical
J301: Arduino_Pinout_01-15; PinHeader_1x15_P2.54mm_Vertical
J302: SPI; PinHeader_1x06_P2.54mm_Vertical
J303: UART; PinHeader_1x04_P2.54mm_Vertical
J304: I2C; PinHeader_2x04_P2.54mm_Vertical
J305: Arduino_Pinout_16-30; PinHeader_1x15_P2.54mm_Vertical
J401: Probe_Vin; TestPoint_2Pads_Pitch5.08mm_Drill1.3mm
J402: JP_RUN; PinHeader_2x03_P2.54mm_Vertical
J403: Probe_Iin; TestPoint_2Pads_Pitch5.08mm_Drill1.3mm
J404: Probe_DAC_A; TestPoint_2Pads_Pitch5.08mm_Drill1.3mm
J405: Probe_DAC_B; TestPoint_2Pads_Pitch5.08mm_Drill1.3mm
J406: OPAMP_Vout; TestPoint_2Pads_Pitch5.08mm_Drill1.3mm
J407: Probe_Iout; TestPoint_2Pads_Pitch5.08mm_Drill1.3mm
J408: Probe_Vout; TestPoint_2Pads_Pitch5.08mm_Drill1.3mm
J409: OPAMP_Iout; TestPoint_2Pads_Pitch5.08mm_Drill1.3mm
L401: 7443640330B
Q201, Q202: BC818; SOT-23
Q203: BT169B; TO-92_Inline
Q204: BC808; SOT-23
Q401, Q402: NVTFS6H850NL; ONSEMI-µ8FL
R201, R202, R203, R204: 10k; R_Axial_DIN0207_L6.3mm_D2.5mm_P7.62mm_Horizontal
R205: 470R; R_Axial_DIN0207_L6.3mm_D2.5mm_P7.62mm_Horizontal
R206, R208, R210, R212: 1k; R_Axial_DIN0207_L6.3mm_D2.5mm_P7.62mm_Horizontal
R207, R209, R211: 470R; R_0402_1005Metric
R301, R302: 4.8k; R_Axial_DIN0207_L6.3mm_D2.5mm_P7.62mm_Horizontal
R401: 8.66k; R_0805_2012Metric
R402: 1.1mR; R_2512_6332Metric
R403, R404, R405, R406, R410, R414: 100k; R_0805_2012Metric
R407: 34k; R_0805_2012Metric
R408: 2k; R_0805_2012Metric
R409: 4.8k; R_0805_2012Metric
R411, R413: 3.3k; R_0805_2012Metric
R412: 1mR; R_2512_6332Metric
U201: STM6600; TDFN-12_2x3mm_P0.5mm
U401, U402: MCP602; SOIC-8_3.9x4.9mm_P1.27mm
U403: LTC3786; QFN-16-1EP_3x3mm_P0.5mm_EP1.45x1.45mm_ThermalVias
U404: MCP4822; SOIC-8_3.9x4.9mm_P1.27mm

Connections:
+3V3: J203.1, J203.2, J203.12, J203.13
+5V: A301.30, C401.1, C408.1, C409.1, C414.1, C415.1, J203.4, J203.6, J203.21, J203.22, J203.23, J206.5, J302.2, J303.3, J304.5, J304.6, J305.15, Q202.3, R201.1, R202.1, R204.1, U401.8, U402.8, U404.1
+12V: C402.1, C403.1, C404.1, C405.1, C406.1, C407.1, C412.1, C416.2, J203.10, J203.11, J204.1, J204.2, J204.3, J205.1, J205.2, J205.3, J401.2, J402.1, J403.1, R402.2, U403.2, U403.12
/Controller/D13_16: A301.16, J302.6, J305.1, U404.3
/Controller/I-Sense_IN: J409.1, R301.2, R410.1, U402.1
/Controller/RES_3: A301.3, J301.3
/Controller/SPI-CS: A301.8, J301.8, U404.2
/Controller/SPI-MISO: A301.15, J301.15, J302.5
/Controller/SPI-MOSI: A301.14, J301.14, J302.4, U404.4
/Controller/U-Sense_IN: J406.1, R302.2, U402.6, U402.7
/Plugs_and_Controls/ENBL_A: A301.12, J206.7, J301.12, J402.3
/Plugs_and_Controls/ENBL_JP: J206.10, Q202.1, R208.2
/Plugs_and_Controls/GND_IN: J201.2, J407.2, J408.2, R412.1
/Plugs_and_Controls/PB: J206.1, U201.6
/Plugs_and_Controls/PLASMA_OFF: J206.15, Q204.3, R211.2
/Plugs_and_Controls/PLASMA_ON: J206.13, J207.1, Q203.3, Q204.1, R209.2, R210.2
/Plugs_and_Controls/PWM_IN: A301.11, J202.1, J301.11
/Plugs_and_Controls/PWR_GOOD: J203.8, R207.2, U201.4
/Plugs_and_Controls/PWR_ON: J203.16, Q201.3
/Plugs_and_Controls/SR: J206.3, U201.2
/Plugs_and_Controls/START_BTN: J206.6, R205.2
/Plugs_and_Controls/STOP_BTN: J206.8, J206.9
/Plugs_and_Controls/VDD_IN: F401.2, J201.1, J408.1, R409.2
/Plugs_and_Controls/VSB: C202.1, J203.9, R203.1, U201.1
/SMPS-12-36/U-Sense_int: R407.1, R408.2, U401.3
/SMPS-12-36/VFB: R406.1, U401.7, U403.1
GND: A301.4, A301.29, C201.2, C202.2, C203.2, C301.1, C302.2, C401.2, C402.2, C403.2, C404.2, C405.2, C406.2, C407.2, C408.2, C409.2, C410.1, C411.1, C413.1, C414.2, C415.2, C416.1, C418.1, C419.2, C420.2, C421.2, C422.2, C423.2, C424.2, C425.2, C426.2, D202.1, D203.1, D204.1, D401.2, J202.2, J203.3, J203.5, J203.7, J203.15, J203.17, J203.18, J203.19, J203.24, J204.5, J204.7, J204.8, J205.5, J205.7, J205.8, J206.2, J206.4, J206.12, J206.14, J206.16, J207.2, J301.4, J302.1, J303.4, J304.7, J304.8, J305.14, J401.1, J402.5, J404.2, J405.2, J406.2, J407.1, J409.2, L401.3, Q201.2, Q401.1, R206.1, R208.1, R210.1, R212.1, R408.1, R414.1, U201.12, U401.4, U402.4, U403.6, U403.7, U403.9, U404.5, U404.7
unnamed: A301.1, J301.1, J303.2
unnamed: A301.2, J301.2, J303.1
unnamed: A301.5, J301.5
unnamed: A301.6, J301.6
unnamed: A301.7, J301.7
unnamed: A301.9, J301.9
unnamed: A301.10, J301.10
unnamed: A301.13, J301.13, J302.3
unnamed: A301.17, J305.2
unnamed: A301.18, J305.3
unnamed: A301.19, J305.4
unnamed: A301.20, J305.5
unnamed: A301.21, J305.6
unnamed: A301.22, J305.7
unnamed: A301.23, J304.3, J304.4, J305.8
unnamed: A301.24, J304.1, J304.2, J305.9
unnamed: A301.25, C302.1, J305.10, R302.1
unnamed: A301.26, C301.2, J305.11, R301.1
unnamed: A301.27, J305.12
unnamed: A301.28, J305.13
unnamed: C201.1, U201.5
unnamed: C203.1, U201.3
unnamed: C410.2, R401.1
unnamed: C411.2, R401.2, U403.4
unnamed: C412.2, J403.2, L401.1, R402.1, U403.3
unnamed: C413.2, U403.5
unnamed: C417.1, L401.2, Q401.3, Q402.1, U403.15
unnamed: C417.2, D402.1, U403.13
unnamed: C418.2, D402.2, R403.2, U403.11
unnamed: C419.1, J405.1, R405.1, U401.5
unnamed: C420.1, C421.1, C422.1, C423.1, C424.1, C425.1, F401.1, Q402.3, R407.2
unnamed: C426.1, R409.1, U402.5
unnamed: D201.1, U201.7
unnamed: D201.2, R203.2
unnamed: D202.2, R207.1
unnamed: D203.2, R209.1
unnamed: D204.2, R211.1
unnamed: D401.1, J402.2, J402.4, J402.6, U403.8
unnamed: J404.1, R404.1, U401.2
unnamed: Q201.1, U201.9
unnamed: Q202.2, Q203.1
unnamed: Q203.2, R205.1, R206.2
unnamed: Q204.2, R212.2
unnamed: Q401.2, U403.10
unnamed: Q402.2, U403.14
unnamed: R201.2, U201.11
unnamed: R202.2, U201.10
unnamed: R204.2, U201.8
unnamed: R403.1, U403.16
unnamed: R404.2, U404.8
unnamed: R405.2, U404.6
unnamed: R406.2, U401.1, U401.6
unnamed: R410.2, R411.2, U402.2
unnamed: R412.2, R413.2
unnamed: R413.1, R414.2, U402.3

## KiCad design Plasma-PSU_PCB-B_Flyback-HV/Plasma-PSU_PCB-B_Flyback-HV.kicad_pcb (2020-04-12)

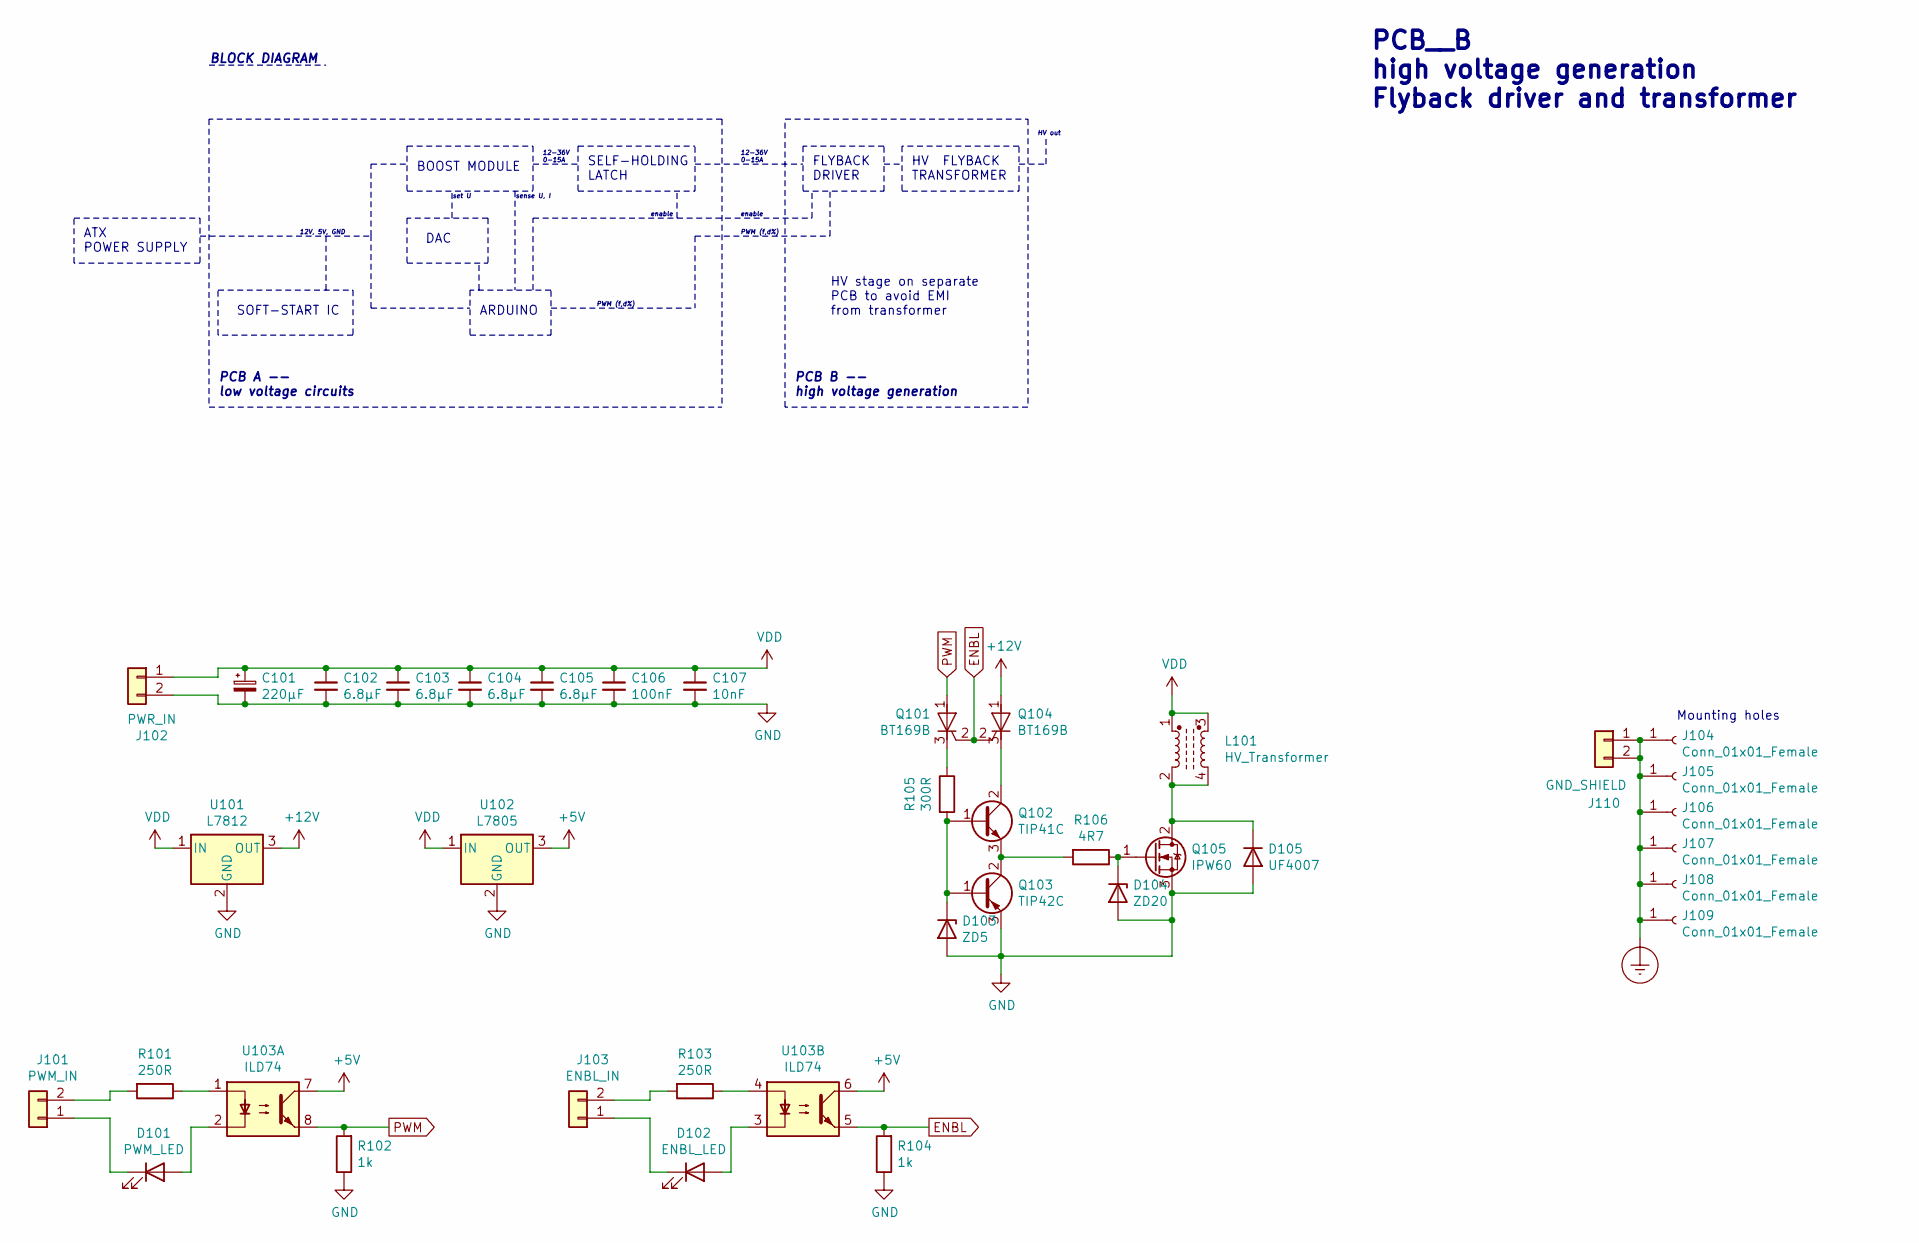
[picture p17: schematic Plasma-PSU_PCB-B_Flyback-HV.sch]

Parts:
C101: 220µF; CP_Radial_D8.0mm_P3.50mm
C102, C103, C104, C105: 6.8µF; C_Disc_D6.0mm_W2.5mm_P5.00mm
C106: 100nF; C_1206_3216Metric
C107: 10nF; C_0805_2012Metric
D101: PWM_LED; LED_0603_1608Metric
D102: ENBL_LED; LED_0603_1608Metric
D103: ZD5; D_DO-41_SOD81_P7.62mm_Horizontal
D104: ZD20; D_DO-41_SOD81_P7.62mm_Horizontal
D105: UF4007; D_DO-41_SOD81_P7.62mm_Horizontal
J101: PWM_IN; PinHeader_1x02_P2.54mm_Vertical
J102: PWR_IN; TerminalBlock_Phoenix_MKDS-3-2-5.08_1x02_P5.08mm_Horizontal
J103: ENBL_IN; PinHeader_1x02_P2.54mm_Vertical
J104, J105, J106, J107, J108, J109: Conn_01x01_Female; MountingHole_3.2mm_M3_Pad_Via
J110: GND_SHIELD; TerminalBlock_Phoenix_MKDS-3-2-5.08_1x02_P5.08mm_Horizontal
L101: HV_Transformer; HF-HV_Transformer_15kV_300W
Q101, Q104: BT169B; TO-92_Inline
Q102: TIP41C; TO-220-3_Vertical
Q103: TIP42C; TO-220-3_Vertical
Q105: IPW60; TO-247-3_Vertical
R101, R103: 250R; R_0603_1608Metric
R102, R104: 1k; R_0603_1608Metric
R105: 300R; R_0603_1608Metric
R106: 4R7; R_Axial_DIN0207_L6.3mm_D2.5mm_P7.62mm_Horizontal
U101: L7812; TO-220-3_Vertical
U102: L7805; TO-220-3_Vertical
U103: ILD74; DIP-8_W7.62mm

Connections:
+5V: U102.3 (OUT), U103.6, U103.7
+12V: Q104.1 (A), U101.3 (OUT)
ENBL: Q101.2 (G), Q104.2 (G), R104.2, U103.5
Earth_Protective: J104.1, J105.1, J106.1, J107.1, J108.1, J109.1, J110.1, J110.2
GND: C101.2, C102.2, C103.2, C104.2, C105.2, C106.2, C107.2, D103.2 (A), D104.2 (A), D105.2 (A), J102.2, Q103.3 (E), Q105.3 (S), R102.1, R104.1, U101.2 (GND), U102.2 (GND)
unnamed: D101.1 (K), J101.1
unnamed: D101.2 (A), U103.2
unnamed: D102.1 (K), J103.1
unnamed: D102.2 (A), U103.3
unnamed: D103.1 (K), Q102.1 (B), Q103.1 (B), R105.2
unnamed: D104.1 (K), Q105.1 (G), R106.1
unnamed: D105.1 (K), L101.2, L101.4, Q105.2 (D)
unnamed: J101.2, R101.2
unnamed: J103.2, R103.2
unnamed: Q101.3 (K), R105.1
unnamed: Q102.2 (C), Q104.3 (K)
unnamed: Q102.3 (E), Q103.2 (C), R106.2
unnamed: R101.1, U103.1
unnamed: R103.1, U103.4
PWM: Q101.1 (A), R102.2, U103.8
VDD: C101.1, C102.1, C103.1, C104.1, C105.1, C106.1, C107.1, J102.1, L101.1, L101.3, U101.1 (IN), U102.1 (IN)

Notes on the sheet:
HV stage on separate PCB to avoid EMI from transformer
PCB__B high voltage generation Flyback driver and transformer
ATX POWER SUPPLY
SOFT-START IC
BOOST MODULE
ARDUINO
DAC
FLYBACK DRIVER
HV FLYBACK TRANSFORMER
set U
sense U, I
12-36V 0-15A
PWM (f,d%)
HV out
PCB A -- low voltage circuits
PCB B -- high voltage generation
BLOCK DIAGRAM
SELF-HOLDING LATCH
enable
12V, 5V, GND
Mounting holes

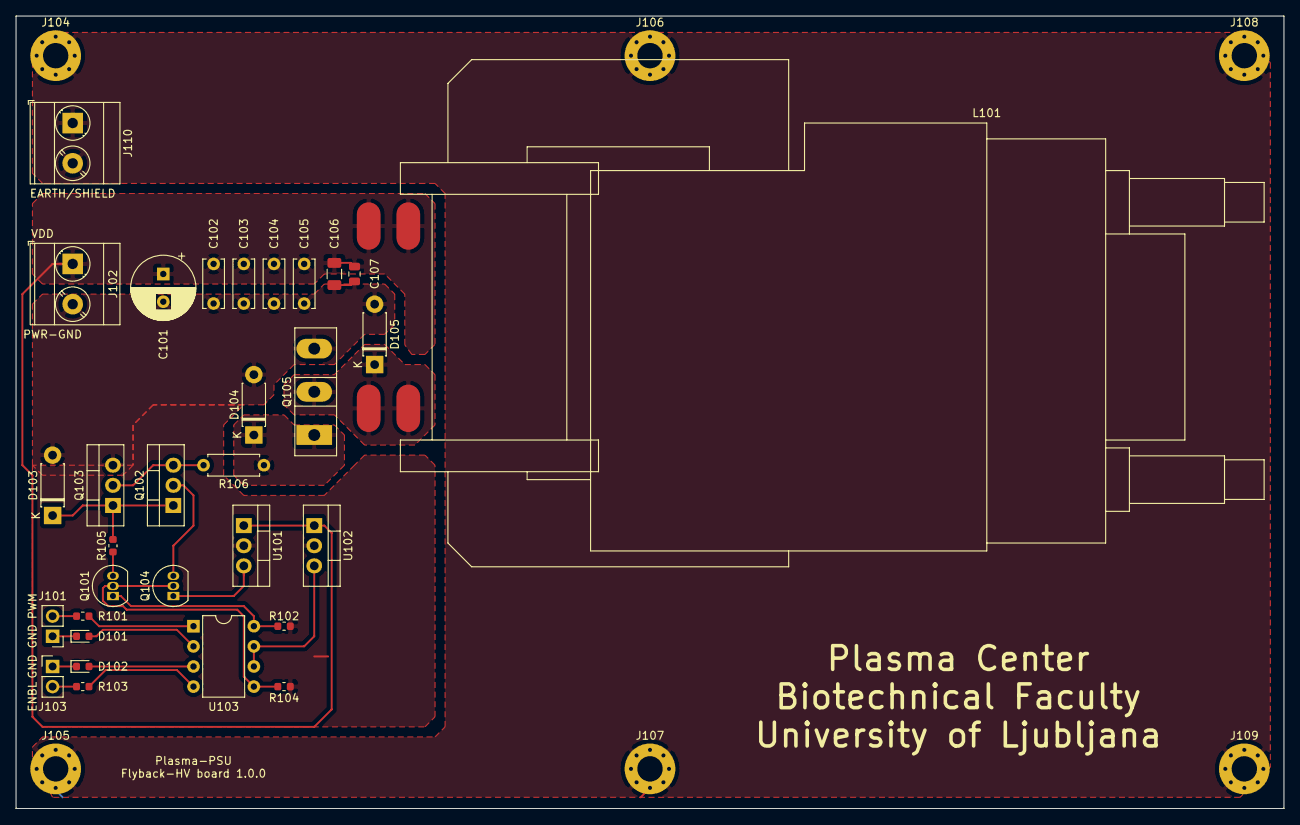
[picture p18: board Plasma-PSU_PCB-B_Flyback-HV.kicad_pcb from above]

Board: 2 copper layers, 160.0 x 100.0 mm, 37 parts (0 on the bottom side), 21 nets.

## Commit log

2020-04-06 Intro Eurocard & Arduino
    - Construction step towards circuit on 2x Euroboard PCB
    - Replacing Ruideng DVS by own boost circuit
    - Introducing Arduino as controller
    [Controller.sch, Flyback_HV_stage.sch, Plasma-PSU_Eurocard_Flyback.kicad_pcb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]
2020-04-06 Include LTC3786 regulator IC
    [Flyback_HV_stage.sch, SMPS-12-36.sch]
2020-04-06 LTC3786 arranged according to datasheet
    [Plasma-PSU_Eurocard_Flyback.kicad_pcb, SMPS-12-36.sch]
2020-04-06 Filter caps & Rsense revised
    [SMPS-12-36.sch]
2020-04-07 Block diagram, Connectivity, Isolation
    - First page reservered for block diagram
    - Connectors moved to separate sheet
    - Opto-isolators for signal inputs on HV board
    - Fuse added to SMPS
    - Pinheader for Arduino pin-out, UART, I2C, SPI
    [Controller.sch, Flyback_HV_stage.sch, Plasma-PSU_Eurocard_Flyback.sch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]
2020-04-07 STM6600 power-up included
    An STM6600 IC is now used to enable stand-by and touch-button operation
    [Controller.sch, Plugs_and_Controls.sch]
2020-04-07 Block diagram included
    [Plasma-PSU_Eurocard_Flyback.sch]
2020-04-08 Filters for sense signals
    - RC filters on U-sense and I-sense included
    - Block diagram refined
    [Controller.sch, Flyback_HV_stage.sch, Plasma-PSU_Eurocard_Flyback.sch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]
2020-04-08 DAC sets U_out
    DAC converter in SMPS sheet sets boost modules output voltage.
    [Controller.sch, Plasma-PSU_Eurocard_Flyback.sch, SMPS-12-36.sch]
2020-04-08 Datasheets included
    [Plasma-PSU_Eurocard_Flyback.sch, Plugs_and_Controls.sch]
2020-04-08 SMPS & Shunt selected
    [MOSFET power calculation.xlsx, Plasma-PSU_Eurocard_Flyback.sch, SMPS-12-36.sch]
2020-04-08 Footprints added
    All footprints included, except:
    - Boost Inductor
    - 60A fuse holder
    [Controller.sch, Flyback_HV_stage.sch, Plasma-PSU_Eurocard_Flyback.kicad_pcb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]
2020-04-11 Testpoints & SMPS jumper included
    [SMPS-12-36.sch]
2020-04-11 KiCad files split into PCB-A and PCB-B
    - PCB-A remains with controller & smps as was, but renamed as ./Plasma-PSU_PCB-A_Power-Controller
    - PCB-B, namely the HV generation, is moved into ./Plasma-PSU_PCB-B_Flyback-HV
    - PCB tracing created for PCB-B
    [Controller.sch, Flyback_HV_stage.sch, MOSFET power calculation.xlsx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]
2020-04-12 Flyback PCB w/ SMD & Earth
    - Changed most resistors to SMD
    - Included Earth planes separate from GND for shielding
    [Plasma-PSU_PCB-B_Flyback-HV.kicad_pcb, Plasma-PSU_PCB-B_Flyback-HV.sch]
2020-04-12 Gerber files Flyback-HV for inquiry
    [Plasma-PSU_PCB-B_Flyback-HV-B_Cu.gbr, Plasma-PSU_PCB-B_Flyback-HV-B_Mask.gbr, Plasma-PSU_PCB-B_Flyback-HV-B_Paste.gbr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]
2020-04-16 BOM PCB-B arranged
    Order numbers for Farnell-element14 and for Mouser
    [Plasma-PSU_PCB-B_Flyback-HV.csv, Plasma-PSU_PCB-B_Flyback-HV.xlsx, SMPS-12-36.sch]
2020-04-16 Power Inductor updated
    [Controller.sch, Inductor calculations.xlsx, Plasma-PSU_PCB-A_Power-Controller.kicad_pcb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]
2020-04-16 Test-PCB created for Arduino+DAC
    Separate test board created, on which the following parts will be tested:
    - Arduino
    - DAC
    - OP AMP
    - Soft-start IC
    - ATX 24pin power connector
    [Controller.sch, MOSFET power calculation.xlsx, Plugs_and_Controls.sch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]
2020-04-16 Improved Test-PCB Arduino-DAC
    [Plugs_and_Controls.sch, Test-PCB_for_Arduino-DAC.kicad_pcb]
2020-04-17 FET & L revision w/ LTpowerCAD
    LTpowerCAD tool used to revise selection of:
    - main inductor
    - control FET
    - sync FET
    - input and output capacitor banks
    [Plugs_and_Controls.sch, SMPS-12-36.sch]
